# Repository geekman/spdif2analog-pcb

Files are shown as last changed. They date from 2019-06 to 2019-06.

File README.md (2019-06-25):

SPDIF Optical to Analog Converter
==================================

This is a device that converts uncompressed PCM audio stream from an OPTICAL
OUT connection into analog audio that can be connected to a LINE IN of some
device.
It does NOT support decoding 5.1 audio streams.

assembled device

Design considerations and other details were written up in a blog post here: 
<https://irq5.io/2011/03/10/optical-to-analog-audio-converter/>

Files
------

The hardware design files are in the *CadSoft EAGLE* format, 
now known as [Autodesk EAGLE](https://www.autodesk.com/products/eagle/overview).
You can download and use EAGLE for free to open the files, view the schematics 
and generate Gerber files for manufacture.

For convenience, generated files _may_ have been made available under the 
**Releases** or **Downloads** section of the repository, but otherwise, 
you have to do it yourself.

Some footprints used in the design may have come from the 
[SparkFun EAGLE libraries](https://github.com/sparkfun/SparkFun-Eagle-Libraries).

License
--------

**spdif2analog is licensed under the TAPR Open Hardware License (https://www.tapr.org/OHL).**

Copyright (C) 2011 Darell Tan

The TAPR Open Hardware License ("OHL") agreement provides a legal
framework for Open Hardware projects.
The OHL addresses unique issues involved in the creation of tangible,
physical things, but does not cover software, firmware, or code loaded
into programmable devices.
While the terms and conditions of the License take precedence, here are some
key points, provided solely for convenience:

*  You may modify the documentation and make products based upon it.

*  You may use products for any legal purpose without limitation.

*  You may distribute products you make to third parties, if you either
   include the documentation on which the product is based, or make it
   available without charge for at least three years to anyone who requests
   it.

*  You may distribute unmodified documentation, but you must include the
   complete package as you received it.

*  You may distribute modified documentation or products based on it, if you 
   license your modifications under the OHL and include those modifications.

*  Any time the OHL requires you to make documentation available to
   others, you must include all the materials you received from the
   upstream licensors.  In addition, if you have modified the
   documentation, you must identify the modifications in a text file,
   and include any new files you created.

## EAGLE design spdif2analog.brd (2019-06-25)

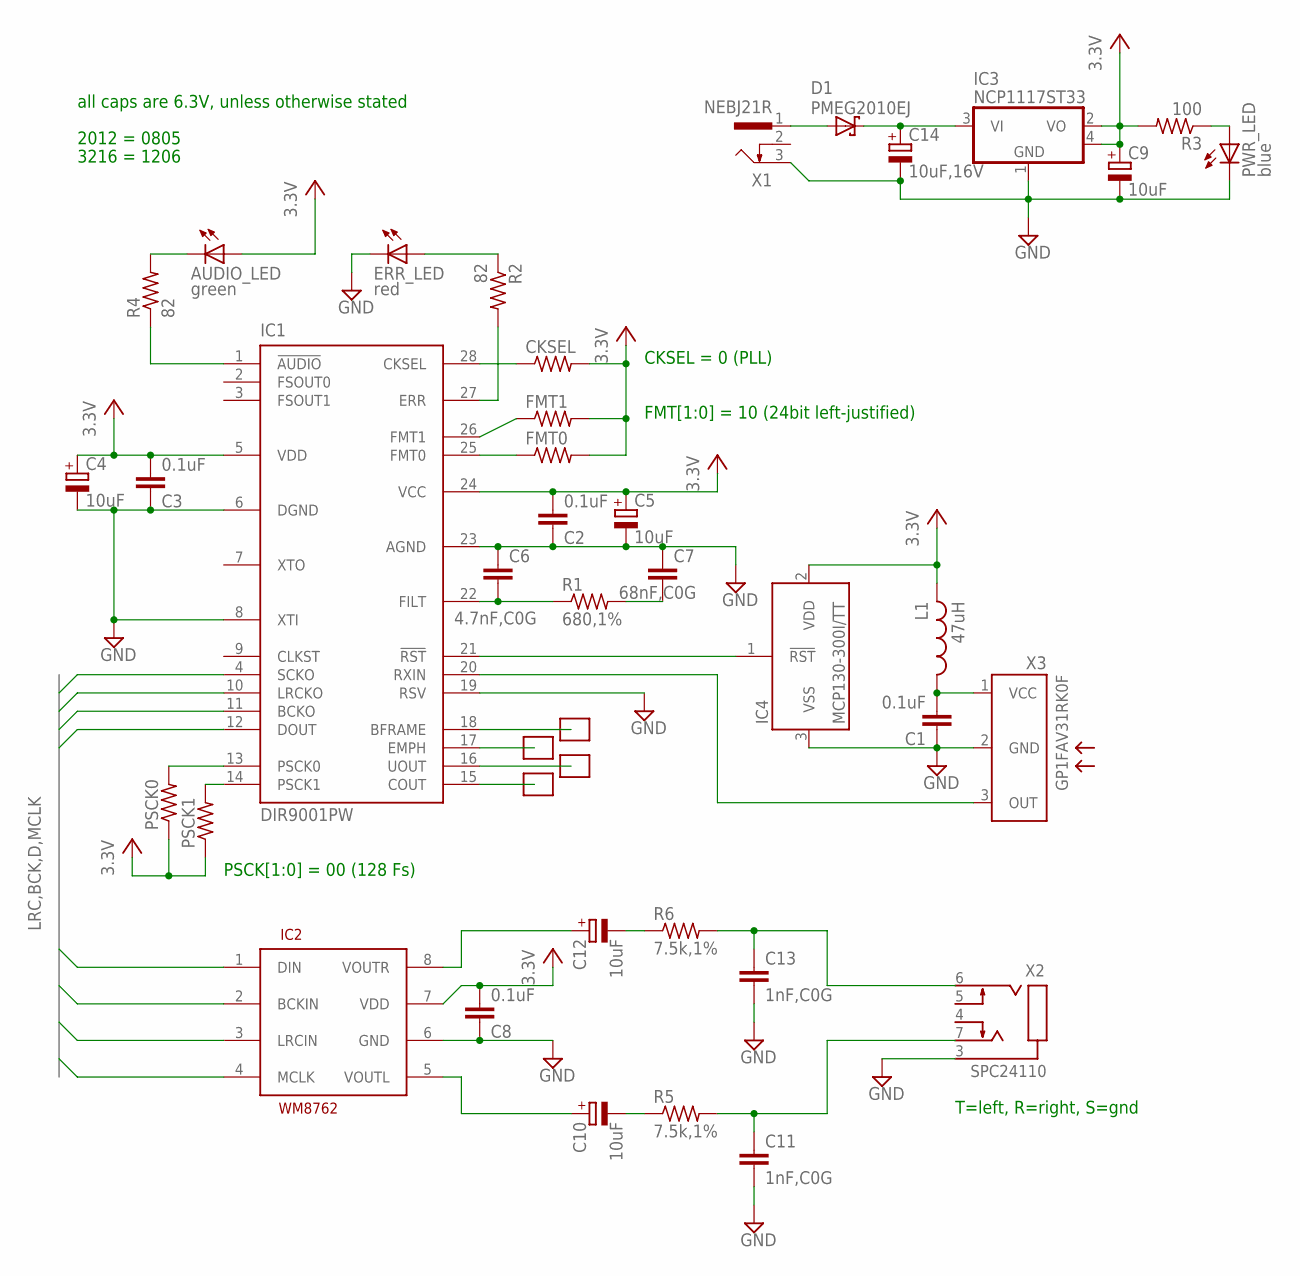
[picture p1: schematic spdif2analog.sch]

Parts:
AUDIO_LED: green; CHIPLED_0805
C1, C2, C3, C8: 0.1uF; C0805
C4, C5, C9, C10, C12: 10uF; A/3216-18R
C6: 4.7nF,C0G; C0805
C7: 68nF,C0G; C025_050-035X075
C11, C13: 1nF,C0G; C0805
C14: 10uF,16V; A/3216-18R
CKSEL: 5.1k; R0805
D1: PMEG2010EJ; SOD-323
ERR_LED: red; CHIPLED_0805
FMT0, FMT1: 5.1k; R0805
IC1: DIR9001PW; PW_R-PDSO-G28
IC2: WM8762; SOIC8
IC3: NCP1117ST33; SOT-223
IC4: MCP130-300I/TT; SOT-23-3
L1: 47uH; L2012C
PSCK0, PSCK1: 5.1k; R0805
PWR_LED: blue; CHIPLED_0805
R1: 680,1%; R0805
R2, R4: 82; R0805
R3: 100; R0805
R5, R6: 7.5k,1%; R0805
U$1, U$2, U$3, U$4: PAD.015
X1: NEBJ21R
X2: SPC24110
X3: GP1FAV31RK0F

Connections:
3.3V: AUDIO_LED.A, C2.2, C3.2, C4.+, C5.+, C8.2, C9.+, CKSEL.2, FMT0.2, FMT1.2, IC1.5 (VDD), IC1.24 (VCC), IC2.7 (VDD), IC3.2 (VO), IC3.4 (TAB), IC4.2 (VDD), L1.2, PSCK0.1, PSCK1.1, R3.2
BCK: IC1.11 (BCKO), IC2.2 (BCKIN)
D: IC1.12 (DOUT), IC2.1 (DIN)
GND: C1.1, C2.1, C3.1, C4.-, C5.-, C6.1, C7.1, C8.1, C9.-, C11.2, C13.2, C14.-, ERR_LED.C, IC1.6 (DGND), IC1.8 (XTI), IC1.19 (RSV), IC1.23 (AGND), IC2.6 (GND), IC3.1 (GND), IC4.3 (VSS), PWR_LED.C, X1.3, X2.3 (SLEEVE), X3.2 (GND)
LRC: IC1.10 (LRCKO), IC2.3 (LRCIN)
MCLK: IC1.4 (SCKO), IC2.4 (MCLK)
unnamed: C1.2, L1.1, X3.1 (VCC)
unnamed: IC1.21 (!RST), IC4.1 (!RST)
unnamed: C7.2, R1.2
unnamed: IC1.20 (RXIN), X3.3 (OUT)
unnamed: C6.2, IC1.22 (FILT), R1.1
unnamed: IC1.13 (PSCK0), PSCK0.2
unnamed: D1.2 (A), X1.1
unnamed: IC1.14 (PSCK1), PSCK1.2
unnamed: FMT1.1, IC1.26 (FMT1)
unnamed: FMT0.1, IC1.25 (FMT0)
unnamed: CKSEL.1, IC1.28 (CKSEL)
unnamed: ERR_LED.A, R2.1
unnamed: IC1.27 (ERR), R2.2
unnamed: C10.+, IC2.5 (VOUTL)
unnamed: PWR_LED.A, R3.1
unnamed: C12.+, IC2.8 (VOUTR)
unnamed: C13.1, R6.2, X2.6 (RING)
unnamed: C11.1, R5.2, X2.7 (TIP)
unnamed: IC1.18 (BFRAME), U$1.1
unnamed: IC1.17 (EMPH), U$2.1
unnamed: IC1.16 (UOUT), U$3.1
unnamed: IC1.15 (COUT), U$4.1
unnamed: AUDIO_LED.C, R4.2
unnamed: C12.-, R6.1
unnamed: IC1.1 (!AUDIO), R4.1
unnamed: C14.+, D1.1 (C), IC3.3 (VI)
unnamed: C10.-, R5.1

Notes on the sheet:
2012 = 0805
3216 = 1206
FMT[1:0] = 10 (24bit left-justified)
PSCK[1:0] = 00 (128 Fs)
T=left, R=right, S=gnd
all caps are 6.3V, unless otherwise stated
CKSEL = 0 (PLL)

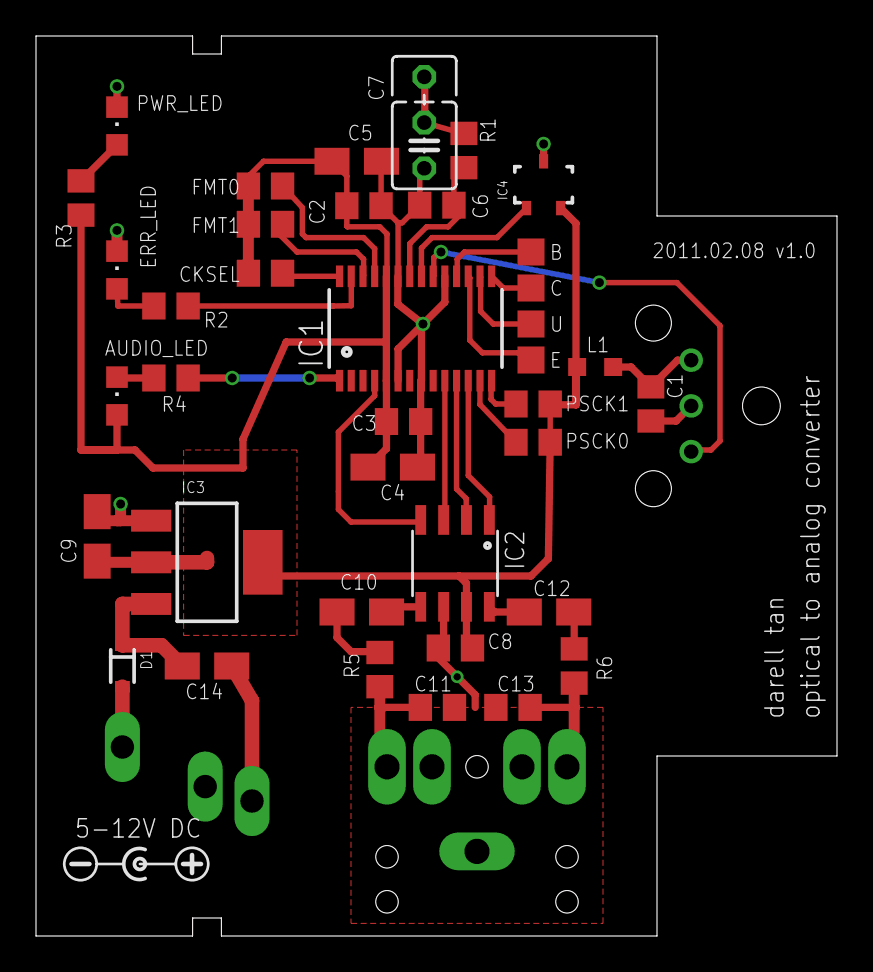
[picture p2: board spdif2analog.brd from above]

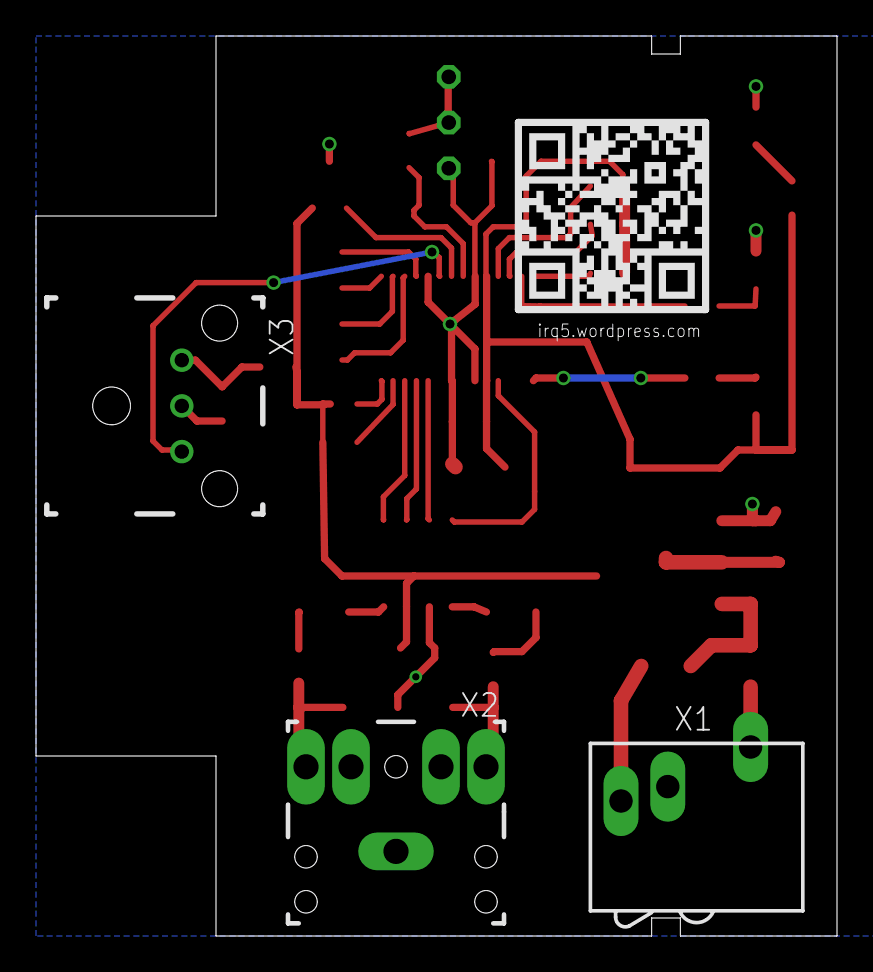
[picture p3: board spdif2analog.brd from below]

Board: 2 copper layers, 44.5 x 50.0 mm, 43 parts (4 on the bottom side), 33 nets.

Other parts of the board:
U$5: SILK-IRQ5_QR_CODE
U$6: 5-12V DC; SILK-DC_JACK_POL_A
